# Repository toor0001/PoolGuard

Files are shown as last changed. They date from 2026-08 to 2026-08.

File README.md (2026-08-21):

# PoolGuard

**Battery-powered pool skimmer monitor for Home Assistant and ESPHome**

[Deutsch](README_DE.md) · English

PoolGuard is a DIY sensor module designed to fit precisely into the lid of an **AstralPool 17.5 L skimmer** and can be glued in place without drilling the original lid. The module measures the distance to the water surface and derives the current pool-water depth and level. It also monitors pool-water temperature. By analysing movement and short-term fluctuations at the water surface, PoolGuard can additionally estimate whether the circulation pump is running. Significantly stronger and more irregular surface movement can indicate that somebody is currently in the pool. Deep sleep and fully powering down the A02YYUW between checks are intended to make one battery charge last for an entire pool season.

## Home Assistant possibilities

PoolGuard exposes values and states that can be used for automations such as:

- switching a pool heat pump on or off based on water temperature;
- disabling the circulation pump when the water level is too low;
- sending a notification when the minimum safe water depth is crossed;
- operating a UV-C lamp only while circulation is actually detected;
- detecting unusually strong pool activity that can indicate somebody is in the pool;
- displaying current water depth, water-level percentage and estimated pool volume.

> **Name and affiliation:** PoolGuard is an independent open-source DIY project. It is not affiliated with, endorsed by or connected to any company, brand or commercial product using the PoolGuard name.

## Design Principles

1. **Reliability:** Prefer “not currently determinable with confidence” over a precise-looking state inferred from ambiguous ultrasound data.
2. **Simple:** Few settings and special cases keep this seasonal device understandable after months away.
3. **Battery efficient:** The ESP measures and decides locally. Wi-Fi/API are enabled only for relevant information or a periodic status report.
4. **Failsafe:** Errors should lead to controlled continuation, retry/backoff or deep sleep; the A02 and Wi-Fi should not remain active indefinitely.
5. **Separation of concerns:** PoolGuard determines physical states. Home Assistant handles notifications, actuators, offline monitoring and derived convenience information.

**PoolGuard/ESP:** water temperature, reliable distance/depth/level/volume, surface and pump motion, bathing activity, Low Water and Sensor Flood Risk. **Home Assistant:** dashboard, reminders, pump shutdown, high-water, pump-mismatch and offline warnings, plus an optional algae-risk advisory. Use only functions that provide clear value.

## Reliable water and motion evaluation

A water-level burst is reliable only when total motion and both burst halves remain below the active Quiet/Pump boundary. Only then are **Distance to Water**, **Water Depth**, **Water Level**, **Pool Volume** and Low Water updated. During waves these values retain the last reliable quiet measurement, while motion, pump, bathing activity and Sensor Flood Risk are still evaluated. A moving burst deliberately means **no new reliable water-level information**.

Reliable depths do not connect on every wake. A report is requested once the change from the last successfully reported reliable value reaches at least 3 mm, compared as rounded integer millimetres. Small changes accumulate: `105.0 → 104.9` no report, `104.8` no report, `104.7` report.

Person-dominated motion provides no pump ON/OFF evidence: bathing activity may be confirmed while the pump state is preserved and ambiguous pump streaks are cleared. All Pump ON/OFF and Person ON/OFF combinations are possible. During strong bathing activity, ultrasound cannot always determine the real pump state unambiguously.

The 180-minute person cooldown starts only after successful transmission. After communication failure, PoolGuard waits five real wakes before a non-critical retry uses Wi-Fi again; local measurement continues. A new person alert, Low Water OFF→ON or Sensor Flood Risk OFF→ON may bypass backoff once. If that attempt fails, normal backoff applies again.

**Sensor Flood Risk** protects the ultrasound sensor mounted close to the water; it is not a precise water-level measurement. It uses the robust lower distance quantile from at least 11 samples, so one small outlier is insufficient. The installation-dependent mechanical default clearance is 5.0 cm; clear uses 1.0 cm hysteresis and requires a reliable quiet burst. ON requires two different real wakes, and Maintenance bursts in one boot cannot count repeatedly. It adds no wakes, bursts or flash writes. The 5 cm must match the actual mounting and is unrelated to motion calibration.

An independent RTC wake sequence protects wake-based confirmations from repeated Maintenance measurements. Known physical limitation: while a continuously running pump remains above the Quiet boundary, new reliable water-level values normally cannot be obtained; Low Water is therefore typically confirmed during quiet or pump-off phases.

## Parts

| Part | Purpose | Link |
|---|---|---|
| Seeed Studio XIAO ESP32-C3 | Microcontroller / ESPHome |  |
| USB-C breakout cable | Power / connection | |
| DFRobot A02YYUW | Distance measurement to the water surface | |
| Waterproof DS18B20 | Pool-water temperature |  |
| Protected 18650 Li-ion cell | Power supply | – |
| 18650 battery holder | Battery mounting |  |
| **Pololu Mini MOSFET Slide Switch LV #2810** | Fully powers down the A02YYUW during deep sleep | [Pololu](https://www.pololu.com/product/2810) |

> **Affiliate disclosure:** Some product links may be affiliate links. If you purchase through one of them, I may receive a small commission at no additional cost to you.

## A02YYUW power switching and Controlled Mode

The A02YYUW is powered through a **Pololu Mini MOSFET Slide Switch with Reverse Voltage Protection, LV (#2810)**.

```text
XIAO 3.3 V  -------- VIN   Pololu 2810
XIAO GND    -------- GND   Pololu 2810
D2 / GPIO4  -------- ON    Pololu 2810
Pololu VOUT -------- VCC   A02YYUW
A02YYUW GND -------- GND
A02YYUW TX  -------- D7 / GPIO20 (UART RX)
A02YYUW RX  -------- D1 / GPIO3 (control/trigger line)
```

**Important:** PoolGuard uses all four A02YYUW wires. The fourth wire (A02 RX, yellow) is not left unused; it connects to **D1/GPIO3**. PoolGuard uses this line to operate the sensor in UART Controlled Mode and explicitly trigger measurements. A02 TX (white) returns the measurement frames to D7/GPIO20.

Wire colours on the verified build are: A02 red/VCC to Pololu VOUT, black/GND to common ground, white/TX to D7/GPIO20, and yellow/RX control to D1/GPIO3. Pololu ON is connected to D2/GPIO4. DS18B20 Data is connected to D3/GPIO5 with a 4.7 kΩ pull-up to 3.3 V.

- **D2 / GPIO4 HIGH:** A02YYUW powered on
- **D2 / GPIO4 LOW or high-impedance:** A02YYUW powered off
- **D1 / GPIO3:** Controlled-Mode trigger for A02 RX
- during deep sleep the A02YYUW remains unpowered

Set the Pololu's physical slide switch to off so ESPHome can control its ON pin. The DS18B20 data wire uses D3/GPIO5 with a 4.7 kΩ pull-up to 3.3 V.

The DYP UART-Controlled protocol has been successfully verified on the physical PoolGuard. GPIO3 normally stays high. After the Pololu powers the sensor and its startup delay has elapsed, the ESP sends repeated falling edges to A02 RX. Each edge explicitly requests a measurement. PoolGuard then receives the `FF Data_H Data_L Checksum` frame through A02 TX/GPIO20. There are more than 70 ms between triggers; real tests produced approximately 50 valid frames per five-second burst. The A02 is then fully powered down again. The sensor therefore does not transmit continuously and is active only during short measurement windows, which is a key part of the low-power design.

## Measurement and low-power operation

**Measurement Interval** configures the desired time from one normal wake to the next from 1 to 15 minutes; the default is 2 minutes. PoolGuard subtracts the current wake's active runtime from this period before entering deep sleep, so the measurement time is not simply added to the configured interval. Shorter intervals react faster but consume more battery.

Every normal wake initially keeps Wi-Fi disabled, powers the A02 only for its controlled-UART burst, evaluates the samples locally and switches the A02 off again. **Periodic Report Every** selects 1 to 120 wakes and defaults to 30, or about one report per hour at two-minute intervals. A cumulative difference of at least 3 rounded millimetres in reliable water depth and relevant state changes report earlier. The 180-minute person cooldown starts only after successful transmission. A failed non-critical report waits five real wakes before trying Wi-Fi again; new critical ON events may bypass this RTC-only backoff. A successful API report resets it completely.

Both interval numbers use `restore_value` and survive a complete battery disconnect. ESPHome writes them only when the user changes them. Measurements, the normal wake counter and runtime state are not written to flash each wake; the counter and pending reported states remain in RTC memory.

### Home Assistant state and sleep status

Before a connected sleep transition, PoolGuard publishes **PoolGuard Status = Sleeping / Offline** and calls `deep_sleep.enter` directly. It deliberately does not disable Wi-Fi first: ESPHome must close the native API as an expected deep-sleep disconnect. Home Assistant can then keep the last successfully reported measurement values available while the device sleeps.

The status entity reports **Initial Setup**, **Measuring**, **Reporting**, **Maintenance**, or **Sleeping / Offline**. During an ordinary offline wake, Home Assistant cannot see the brief Measuring phase because starting Wi-Fi just to announce it would defeat the low-power design; the retained status therefore remains Sleeping / Offline from HA's perspective. For the same reason there is no misleading firmware `Device Awake` binary sensor. Use HA's integration connectivity for live reachability and PoolGuard Status for the intentional operating state.

<p align="center">
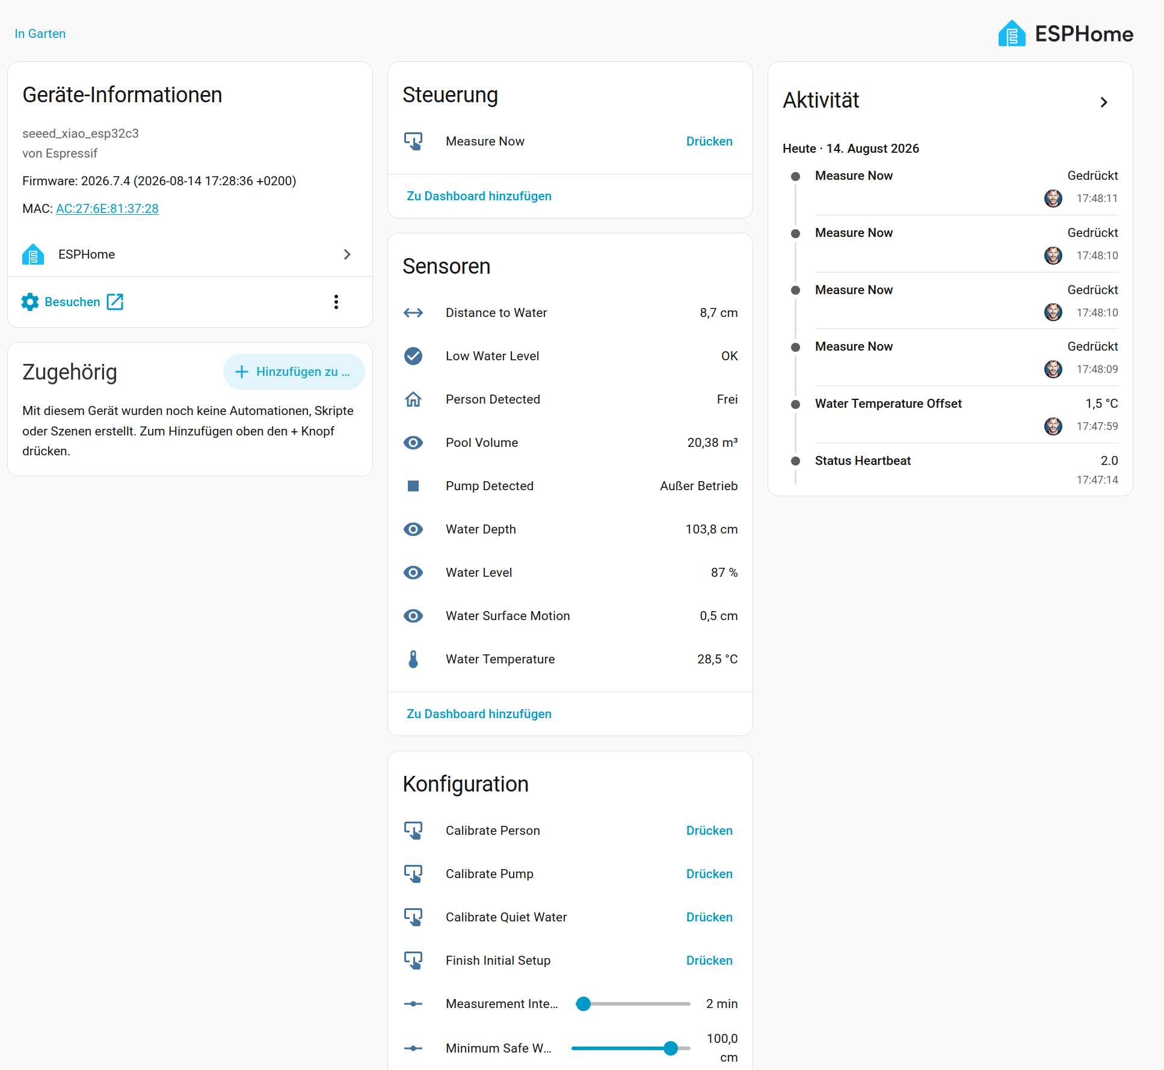
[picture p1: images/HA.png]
PoolGuard ESPHome integration in Home Assistant with retained sensor values
  <br>
  <em>PoolGuard in Home Assistant: Even while <code>Sleeping / Offline</code>, the last successfully transmitted measurements remain available.</em>
</p>

Use native HA cards in three groups: **Status** with temperature, depth, PoolGuard Status, Connection/No Data, Low Water, Sensor Flood Risk, Pump and Bathing Activity; **Algae Risk** as a Low/green, Elevated/yellow or High/red traffic-light tile without percentages; **Controls** with Maintenance, Pump and UV. A Water Depth gauge may have installation-specific colour bands but is convenience UI only—PoolGuard or HA automations make protection decisions. Keep **Status Heartbeat**/`last_updated` visible in diagnostics. No `custom:button-card` is required.

### Lovelace dashboard

<p align="center">
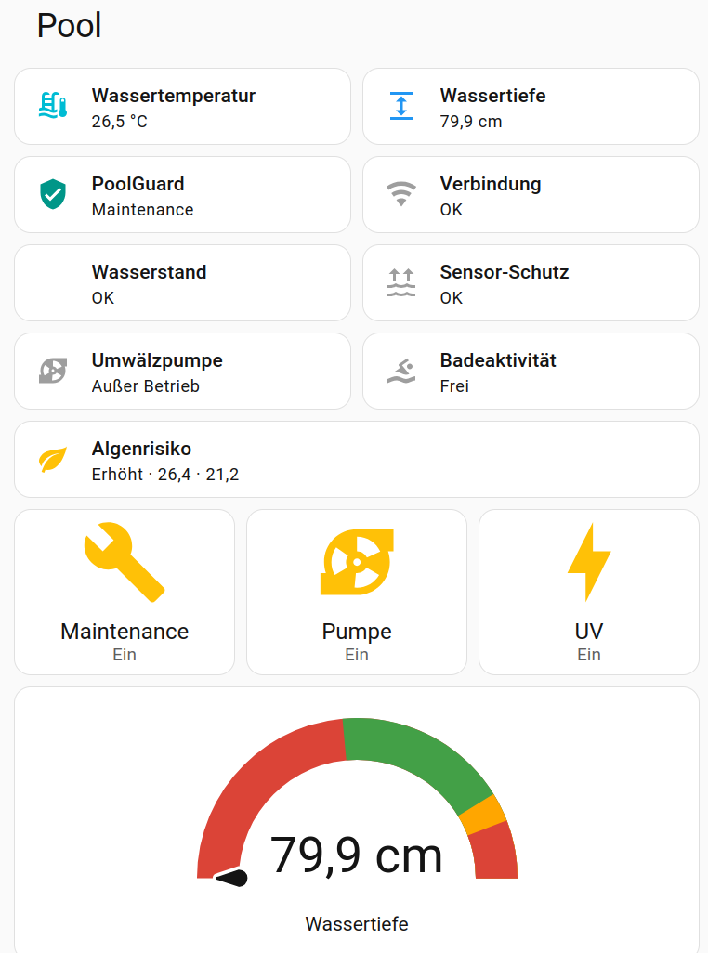
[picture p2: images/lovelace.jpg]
Final PoolGuard Lovelace dashboard with status, sensor protection, algae risk, controls and a coloured water-depth gauge
  <br>
  <em>Current PoolGuard dashboard with water temperature and depth, device and connection status, water level, sensor protection, pump, bathing activity, algae risk, Maintenance, pump and UV controls, and a coloured water-depth gauge.</em>
</p>

**Status Heartbeat** changes only after a complete successful report. Its Home Assistant `last_updated` metadata is the **Last Successful Report** time and shows the age of retained measurements without an ESP timestamp or flash write.

The persistent **Water Temperature Offset** ranges from -5.0 to +5.0 °C in 0.1 °C steps and is saved only when changed. For example, if the DS18B20 reads 25.6 °C while a reference thermometer reads 26.8 °C, set the offset to +1.2 °C; **Water Temperature** then reports 26.8 °C. It survives battery replacement. The offset is applied exactly once to a real temperature conversion; a complete report does not feed the already corrected value through the same filter a second time.

OTA remains available whenever PoolGuard is already online in Initial Setup, Maintenance Mode or a report window. The device does not create additional Wi-Fi connections solely for OTA.

## Example: Home Assistant alerts

PoolGuard can be combined with Home Assistant automations to provide several independent safety and notification functions. Keeping these automations separate makes troubleshooting easier and allows each protection function to be enabled, disabled, or adjusted independently.

Actual entity IDs depend on the device name, area and Home Assistant installation. Every ID below is illustrative and must be checked and adapted in HA. Home Assistant notifies, repeats and controls actuators without waking PoolGuard more often. The examples assume these entities:

- `binary_sensor.poolguard_person_detected`
- `binary_sensor.poolguard_low_water_level`
- `binary_sensor.poolguard_pump_detected`
- `binary_sensor.poolguard_sensor_flood_risk`
- `binary_sensor.poolguard_no_data` (HA template)
- `sensor.poolguard_water_depth`
- `sensor.poolguard_water_level`
- `switch.pool_pump`
- `notify.mobile_app_your_phone`

Replace the notification service and pump entity with your own entities.

### 1. Person / bathing activity detected

The firmware already rate-limits person-triggered reports. After one reported person/bathing event, further person-only report requests are suppressed for 180 minutes while local measurements continue. This prevents repeated notifications and unnecessary Wi-Fi/API wake-ups caused by fluctuating water movement.

```yaml
alias: PoolGuard – Person detected
description: Critical notification when PoolGuard detects person/bathing activity.
triggers:
  - trigger: state
    entity_id: binary_sensor.poolguard_person_detected
    from: "off"
    to: "on"

conditions: []

actions:
  - action: notify.mobile_app_your_phone
    data:
      title: "🚨 PoolGuard: Pool activity!"
      message: >-
        PoolGuard detected strong water-surface movement that may indicate
        a person or bathing activity in the pool.
      data:
        push:
          interruption-level: critical

mode: single
```

### 2. Low-water warning

HA notifies immediately, hourly and after an HA restart while Low Water remains active. No long `repeat`/`delay` loop is required.

```yaml
alias: PoolGuard – Low Water Warning
triggers:
  - trigger: state
    entity_id: binary_sensor.poolguard_low_water_level
    from: "off"
    to: "on"
  - trigger: time_pattern
    minutes: "0"
  - trigger: homeassistant
    event: start
conditions:
  - condition: state
    entity_id: binary_sensor.poolguard_low_water_level
    state: "on"
actions:
  - action: notify.mobile_app_your_phone
    data:
      title: "PoolGuard: Water level critical"
      message: >-
        PoolGuard has confirmed a critical water level.

        Trigger depth:
        {{ states('sensor.poolguard_low_water_trigger_depth') }} cm

        Current reliable water depth:
        {{ states('sensor.poolguard_water_depth') }} cm

        Water level:
        {{ states('sensor.poolguard_water_level') }} %
      data:
        push:
          interruption-level: critical
mode: single
```

### 3. Pump safety shutdown on low water

This automation switches the circulation pump off when PoolGuard reports a critical water level.

It also prevents the pump from being switched back on while the low-water condition remains active. This is useful when the pump is controlled by another schedule or automation that could otherwise start it again.

A critical notification is sent every time the automation actually performs a safety shutdown.

```yaml
alias: PoolGuard – Pump safety shutdown
description: >
  Switch off the pool pump when the water level is critical and prevent
  it from being switched back on while the low-water condition remains active.
  Send a critical notification for every safety shutdown.

triggers:
  - trigger: state
    entity_id: binary_sensor.poolguard_low_water_level
    from: "off"
    to: "on"
    id: low_water

  - trigger: state
    entity_id: switch.pool_pump
    from: "off"
    to: "on"
    id: pump_on
  - trigger: homeassistant
    event: start

conditions:
  - condition: state
    entity_id: binary_sensor.poolguard_low_water_level
    state: "on"

  - condition: state
    entity_id: switch.pool_pump
    state: "on"

actions:
  - action: switch.turn_off
    target:
      entity_id: switch.pool_pump

  - action: notify.mobile_app_your_phone
    data:
      title: "🚨 PoolGuard: Pump safety shutdown!"
      message: >-
        The circulation pump was automatically switched off because
        PoolGuard detected a critical water level.

        Water depth:
        {{ states('sensor.poolguard_water_depth') }} cm

        Water level:
        {{ states('sensor.poolguard_water_level') }} %
      data:
        push:
          interruption-level: critical

mode: single
```

### 4. Pump powered but no typical water movement

This is a warning only. PoolGuard cannot know for certain that no water is flowing. Causes may include pump, suction, valve position, hydraulics or calibration. It deliberately does not warn during person/bathing activity or when data is stale.

```yaml
alias: PoolGuard – Pump On Without Water Motion
triggers:
  - trigger: time_pattern
    minutes: "/1"
conditions:
  - condition: state
    entity_id: switch.pool_pump
    state: "on"
  - condition: state
    entity_id: binary_sensor.poolguard_pump_detected
    state: "off"
  - condition: state
    entity_id: binary_sensor.poolguard_person_detected
    state: "off"
  - condition: state
    entity_id: binary_sensor.poolguard_no_data
    state: "off"
  - condition: template
    value_template: >-
      {% set since = [states.switch.pool_pump.last_changed,
        states.binary_sensor.poolguard_pump_detected.last_changed,
        states.binary_sensor.poolguard_person_detected.last_changed] | max %}
      {{ now() - since >= timedelta(minutes=5) }}
  - condition: template
    value_template: >-
      {% set last = this.attributes.get('last_triggered') %}
      {{ last is none or now() - last >= timedelta(minutes=5) }}
actions:
  - action: notify.mobile_app_your_phone
    data:
      title: "PoolGuard: Pump without typical water motion"
      message: "Calibrated pump motion has been absent for at least five minutes. Check pump, flow and valve position."
mode: single
```

### 5. High water level alert

`Distance to Water` updates only from a reliable quiet burst. The example 3 cm threshold depends on installation. No Data prevents repetitions caused by an old frozen value.

```yaml
alias: PoolGuard – Pool Too Full
triggers:
  - trigger: numeric_state
    entity_id: sensor.poolguard_distance_to_water
    below: 3
  - trigger: time_pattern
    minutes: "/15"
  - trigger: homeassistant
    event: start
conditions:
  - condition: numeric_state
    entity_id: sensor.poolguard_distance_to_water
    below: 3
  - condition: state
    entity_id: binary_sensor.poolguard_no_data
    state: "off"
actions:
  - action: notify.mobile_app_your_phone
    data:
      title: "PoolGuard: Pool too full"
      message: >-
        Reliable distance to water:
        {{ states('sensor.poolguard_distance_to_water') }} cm.
        Please check the pool level.
      data:
        push:
          interruption-level: critical
mode: single
```

### 6. Sensor Flood Risk

High Water and Sensor Flood Risk differ deliberately: High Water is a precise quiet-only distance; Flood Risk protects the sensor and may inspect moving water for repeated dangerous approaches.

```yaml
alias: PoolGuard – Sensor Flood Risk
triggers:
  - trigger: state
    entity_id: binary_sensor.poolguard_sensor_flood_risk
    from: "off"
    to: "on"
  - trigger: time_pattern
    minutes: "/15"
  - trigger: homeassistant
    event: start
conditions:
  - condition: state
    entity_id: binary_sensor.poolguard_sensor_flood_risk
    state: "on"
  - condition: state
    entity_id: binary_sensor.poolguard_no_data
    state: "off"
actions:
  - action: notify.mobile_app_your_phone
    data:
      title: "PoolGuard: Sensor flood risk"
      message: >-
        Water is repeatedly getting dangerously close to the ultrasonic sensor.
        Last reliable quiet distance:
        {{ states('sensor.poolguard_distance_to_water') }} cm.
        Check PoolGuard and the pool level.
      data:
        push:
          interruption-level: critical
mode: single
```

### 7. Offline/no-data warning

The ESP being currently unavailable during deep sleep is normal. “Offline” here means no complete successful report for more than three hours. **Status Heartbeat** is the source.

```yaml
template:
  - binary_sensor:
      - name: PoolGuard No Data
        unique_id: poolguard_no_data
        state: >-
          {% set e = states.sensor.poolguard_status_heartbeat %}
          {{ e is not none
             and e.state not in ['unknown', 'unavailable']
             and (now() - e.last_updated).total_seconds() > 10800 }}
```

```yaml
alias: PoolGuard – Offline Warning
triggers:
  - trigger: state
    entity_id: binary_sensor.poolguard_no_data
    from: "off"
    to: "on"
  - trigger: time
    at: "12:00:00"
  - trigger: homeassistant
    event: start
conditions:
  - condition: state
    entity_id: binary_sensor.poolguard_no_data
    state: "on"
actions:
  - action: notify.mobile_app_your_phone
    data:
      title: "PoolGuard: No data"
      message: "No successful report for more than three hours. Check PoolGuard, Wi-Fi and battery."
mode: single
```

10800 seconds is three hours. After an HA restart, `last_updated` may initially look fresh and delay detection; no extra persistent timestamp helper is deliberately required.

### 8. Optional algae-risk indicator

PoolGuard **does not detect algae**. This is only a simplified temperature-based environmental advisory in Home Assistant, not a biological measurement, water analysis or disinfection measurement. It uses pool temperature, a real local outdoor thermometer and the maximum forecast temperature over the next 24 hours. Never derive automatic pump or chemical dosing from it.

```yaml
template:
  - triggers:
      - trigger: homeassistant
        event: start
      - trigger: time_pattern
        minutes: "/15"
    actions:
      - action: weather.get_forecasts
        target:
          entity_id: weather.home
        data:
          type: hourly
        response_variable: pool_weather
    sensor:
      - name: Pool Algae Risk
        unique_id: pool_algae_risk
        icon: mdi:algae
        state: >-
          {% set pool = states('sensor.poolguard_water_temperature') | float(none) %}
          {% set outside = states('sensor.outdoor_temperature') | float(none) %}
          {% set forecast = pool_weather['weather.home'].forecast[:24]
             if pool_weather is defined and 'weather.home' in pool_weather else [] %}
          {% set temps = forecast | map(attribute='temperature')
             | select('defined') | list %}
          {% set forecast_max = temps | max if temps | count > 0 else none %}
          {% if outside is not none and forecast_max is not none %}
            {% set ambient_peak = [outside, forecast_max] | max %}
          {% elif forecast_max is not none %}
            {% set ambient_peak = forecast_max %}
          {% else %}
            {% set ambient_peak = outside %}
          {% endif %}
          {% if pool is none %}
            Unknown
          {% elif pool >= 29 %}
            High
          {% elif pool >= 27 and ambient_peak is not none and ambient_peak >= 27 %}
            High
          {% elif pool >= 24 %}
            Elevated
          {% elif pool >= 22 and ambient_peak is not none and ambient_peak >= 28 %}
            Elevated
          {% else %}
            Low
          {% endif %}
        attributes:
          forecast_peak_24h: "{{ forecast_max }}"
          ambient_peak: "{{ ambient_peak }}"
          uv_index: "{{ state_attr('weather.home', 'uv_index') }}"
```

Logic: unknown pool temperature → Unknown; 29 °C or more → High; 27 °C or more with ambient peak at least 27 °C → High; 24 °C or more → Elevated; 22 °C or more with ambient peak at least 28 °C → Elevated; otherwise Low. Ambient peak is the higher of current local outdoor temperature and the 24-hour forecast maximum.

UV index is exposed only as an informative attribute. It is primarily a human-health indicator, is not linearly related to algae, may inhibit some algae directly, and can indirectly matter in chlorinated pools through faster free-chlorine loss. Without free chlorine, pH and disinfection reserve, a more precise “probability” would be false precision.

```yaml
alias: PoolGuard – Algae Risk Advisory
triggers:
  - trigger: state
    entity_id: sensor.pool_algae_risk
    to: "High"
  - trigger: time
    at: "12:00:00"
conditions:
  - condition: state
    entity_id: sensor.pool_algae_risk
    state: "High"
actions:
  - action: notify.mobile_app_your_phone
    data:
      title: "PoolGuard: elevated algae risk"
      message: "Temperature-based advisory: check water care and filtration time."
mode: single
```

## Maintenance Mode

Create a persistent Home Assistant helper named **PoolGuard Maintenance Mode** with entity ID `input_boolean.poolguard_maintenance_mode` (Settings → Devices & services → Helpers → Create helper → Toggle). The helper, rather than an ESPHome template switch, owns the requested state so an ON command is retained while PoolGuard is asleep and offline.

Turning the helper on is not immediate while PoolGuard sleeps. PoolGuard does not connect to Wi-Fi during each local measurement. It receives the retained request the next time the existing event-driven or periodic reporting logic connects to the Home Assistant API. With the defaults of 2 minutes and 30 wakes, the worst-case delay is approximately one hour; a state-change report can activate it earlier. **PoolGuard Status = Maintenance** confirms that the request has actually reached the device.

While Maintenance Mode is active, PoolGuard stays awake with Wi-Fi/API connected. It performs a powered A02 burst and evaluates water level, pump/activity and person/activity approximately every 5 seconds. Water temperature updates every 30 seconds. The A02 is switched off between bursts. Leaving this mode enabled greatly reduces battery life. Maintenance is really active when **PoolGuard Status** shows Maintenance, the live ESPHome log remains connected and repeated A02 measurement bursts continue to appear in the log. This makes the mode particularly suitable for OTA work and recalibration.

Turn the helper off to leave Maintenance Mode immediately. PoolGuard stops live measurements, switches the A02 off, performs final temperature housekeeping, and returns to its normal deep-sleep cycle without rebooting. The local active flag is intentionally not restored after an unexpected reset: battery-saving operation is the fail-safe default, while the retained HA helper request can be accepted again at a later normal API connection.

Maintenance Mode is a runtime Home Assistant control and does not require reflashing. It remains distinct from Initial Setup Mode, and checking its helper does not add Wi-Fi connections to the local measurement cycle. OTA is available while Maintenance is active; turn the helper back off after OTA or calibration so PoolGuard returns to deep sleep and battery operation.

## Initial Setup Mode

On the first boot in factory state, PoolGuard automatically enters Initial Setup Mode. A flash-backed `initial_setup_completed` flag defaults to false, so Wi-Fi and the Home Assistant API remain enabled and deep sleep is prevented. The A02 stays powered off while idle; it is powered only for an explicit measurement or calibration action. The DS18B20 remains available.

Commissioning requires only one firmware flash:

1. Flash PoolGuard and add it to Home Assistant.
2. Set the water-level reference and minimum safe water depth.
3. Calibrate Quiet Water, Pump and Person if possible.
4. Press **Finish Initial Setup**.

PoolGuard requires a valid water-level reference before it accepts the finish command. Incomplete motion calibration is allowed; a warning is logged and the fallback thresholds remain active. The completion flag is then saved to flash, the A02 is switched off, and normal battery-saving operation begins. Every later power-up, reset and deep-sleep wake starts directly in normal mode. No second flash is required.

To commission the device again, press **Reset Initial Setup** twice within 10 seconds. This confirmation protects against an accidental press. PoolGuard immediately clears the persistent flag, stays awake with Wi-Fi/API enabled, and keeps the A02 off until a measurement or calibration is requested. Existing calibration values are not erased automatically.

## Water-level reference calibration

PoolGuard no longer requires separate "empty" and "full" distance calibration points. **One known real water depth is enough.**

During the automatically entered Initial Setup Mode:

1. Measure the **actual current water depth** in the pool in centimetres.
2. Enter it in **Reference Water Depth**.
3. Press **Measure Now** and check that the A02 distance is plausible.
4. Press **Set Water Level Reference** while the water remains at that level.
5. Set **Minimum Safe Water Depth** to the lowest real depth at which the skimmer can still supply the circulation pump safely.
6. With the pump off, nobody in the pool and the water as calm as possible, press **Calibrate Quiet Water**.
7. Run the pump with nobody in the pool and press **Calibrate Pump**.
8. Create typical swimming/bathing movement and press **Calibrate Person**.
9. Review the three motion profiles and automatically learned thresholds.
10. Press **Finish Initial Setup**.

From then on, PoolGuard calculates the current depth from the change in A02 distance. The distance from the sensor to the pool bottom does not have to be measured separately.

The calculation has been tested on the real pool: a reference depth of 105.5 cm subsequently produced approximately 105.4 cm. Water reference, minimum safe depth, all three motion profiles, learned thresholds and temperature offset are flash-persistent and survive battery replacement.

The default geometry in the YAML is a round pool with **5.0 m diameter** and **120 cm maximum depth**. `Water Level` is calculated as a percentage of that configured maximum depth. `Pool Volume` assumes a cylindrical pool and uses the current measured water depth. With the default geometry, 120 cm corresponds to approximately **23.56 m³**. For another pool, change `pool_diameter_m` and `pool_max_depth_cm` in the YAML. Pools with non-cylindrical bottoms will only get an approximate volume.

## Guided motion calibration

Pump and pool-activity detection depend heavily on the actual skimmer, pump flow, water level and pool geometry. PoolGuard therefore includes guided calibration instead of relying only on fixed thresholds.

In Initial Setup Mode, run these three buttons in order if possible:

1. **Calibrate Quiet Water** – pump off and nobody in the pool.
2. **Calibrate Pump** – circulation pump running, nobody in the pool.
3. **Calibrate Person** – normal swimming/bathing movement in the pool.

Each phase measures about 60 seconds and stores the median motion profile. Motion is evaluated from a trimmed sample span so single outliers or splashes have less influence than a raw min/max range. If the profiles are clearly ordered `quiet < pump < person`, PoolGuard automatically calculates the pump and person/activity thresholds. If they overlap, the previous or fallback thresholds remain active.

The three values describe increasing water-surface movement: Quiet Motion is baseline noise, Pump Motion is normal circulation, and Person Motion is typical bathing activity. Profiles of Quiet 0.50 cm, Pump 0.90 cm and Person 1.45 cm are formally ordered. PoolGuard puts the pump threshold halfway between Quiet and Pump (0.70 cm), but the person entry threshold 65% of the way from Pump to Person (about 1.26 cm); clearing uses the midpoint. Firmware checks strict ordering only, not statistical separation. Closely spaced profiles can therefore be valid yet hard to distinguish in practice.

### Recalibrating individual profiles later

A complete recalibration is not required when only one real-world operating condition has changed. The three profiles can be measured **individually**. Turn on the Maintenance helper and wait until **PoolGuard Status = Maintenance**, then run only the calibration you want to update.

Example: if the running circulation pump is incorrectly classified as a person/bathing activity, leave the pump running under normal real conditions and run **Calibrate Pump** again. Quiet Water and Person do not automatically need to be recalibrated. Afterwards review `Calibration Pump Motion`, `Calibration Person Motion`, `Active Pump Motion Threshold` and `Active Person Motion Threshold`. If the new pump profile reaches or exceeds the person profile, the motion patterns overlap; in that case the person calibration should also be reviewed under realistic conditions.

**Reset Motion Calibration** is not required for normal recalibration. Use it only when you intentionally want to discard all stored motion profiles. After recalibration, turn the Maintenance helper off so PoolGuard returns to normal deep-sleep operation.

Motion calibration is optional for finishing initial setup. If it cannot be completed, PoolGuard logs a warning and continues with its fallback thresholds. After calibration, press **Finish Initial Setup** to begin normal battery-saving operation.

> **Important:** PoolGuard does not detect a person directly. It classifies water-surface motion. Pump/activity detection is therefore an experimental indication and must not be used as a safety system or substitute for pool supervision.

## Mechanical concept

The housing body sits inside the skimmer and is fixed to the side ribs using suitable neutral-curing silicone. The original centre rib remains intact. The body is intentionally **slightly sloped towards the inside of the skimmer**, so any water that reaches the housing can drain back into the skimmer instead of collecting on the body. The removable lower lid carries the electronics:

- battery holder and ESP on the dry/internal side;
- A02YYUW on the water-facing side;
- feed-through for the DS18B20 cable.

The current printable files are available in [`3D-Files/`](3D-Files/). I use a Bambu Lab A1 Mini.

<p align="center">
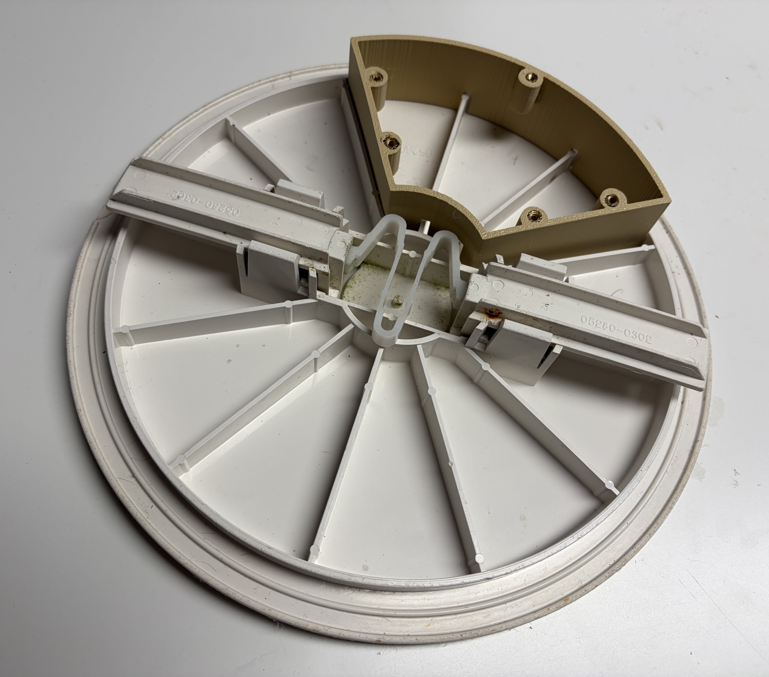
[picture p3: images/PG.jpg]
PoolGuard mechanical housing concept
  <br>
  <em>PoolGuard housing concept for the skimmer lid and removable electronics carrier.</em>
</p>

## Moisture protection and silica gel

PoolGuard sits only a few centimetres above the water surface. Even without direct water ingress, high humidity and temperature changes can cause condensation. A small closed **silica-gel desiccant sachet** inside the electronics compartment is therefore useful as an additional moisture buffer. For the small PoolGuard enclosure, roughly **5–10 g** in total is a practical starting point if the sachet can be secured without stressing components or electrical contacts.

Silica gel is not chemically "used up", but it gradually becomes saturated with water and then loses its effectiveness. Regenerable sachets, ideally with a humidity indicator, can be inspected during seasonal maintenance and dried/regenerated according to the manufacturer's instructions or replaced. There is no honest fixed lifetime in days for PoolGuard: it depends heavily on how open the enclosure is to humid outside air, pool and air temperature, and day/night temperature swings.

Do not use loose granules and **do not use table salt**. Silica gel also does not replace protection against direct splashes or dripping water. The complete electronics enclosure should not simply be covered in silicone or fully potted in epoxy; obvious ingress paths and cable entries can instead be sealed selectively.

More detail: [Moisture, condensation and silica gel](docs/ENVIRONMENT.md).

## Final assembly

<table>
  <tr>
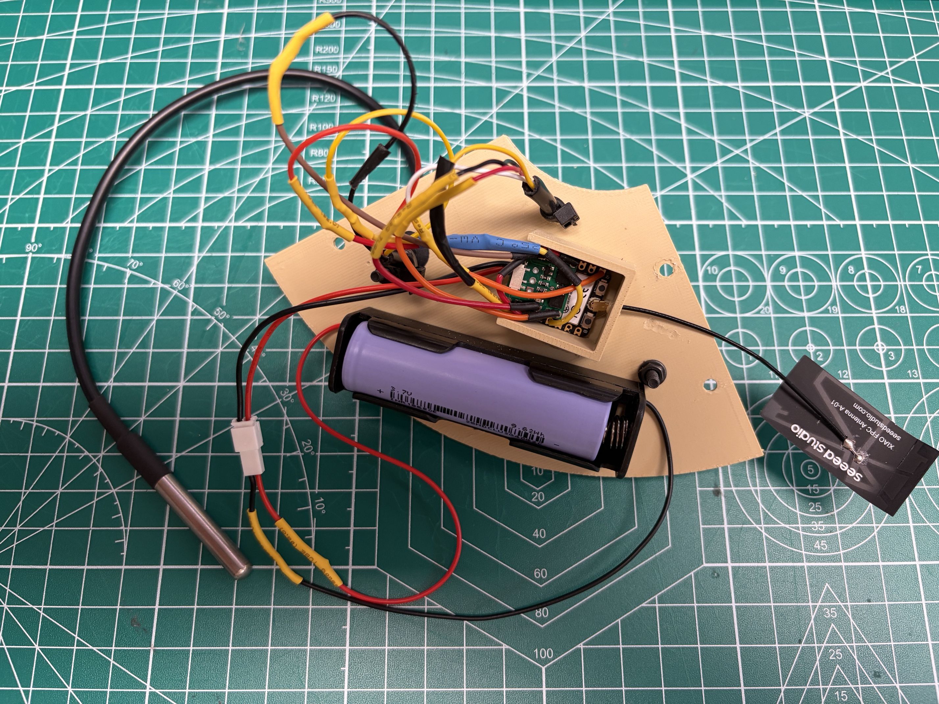
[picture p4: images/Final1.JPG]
PoolGuard electronics carrier with battery, controller and sensors
    <td width="50%" align="center"></td>
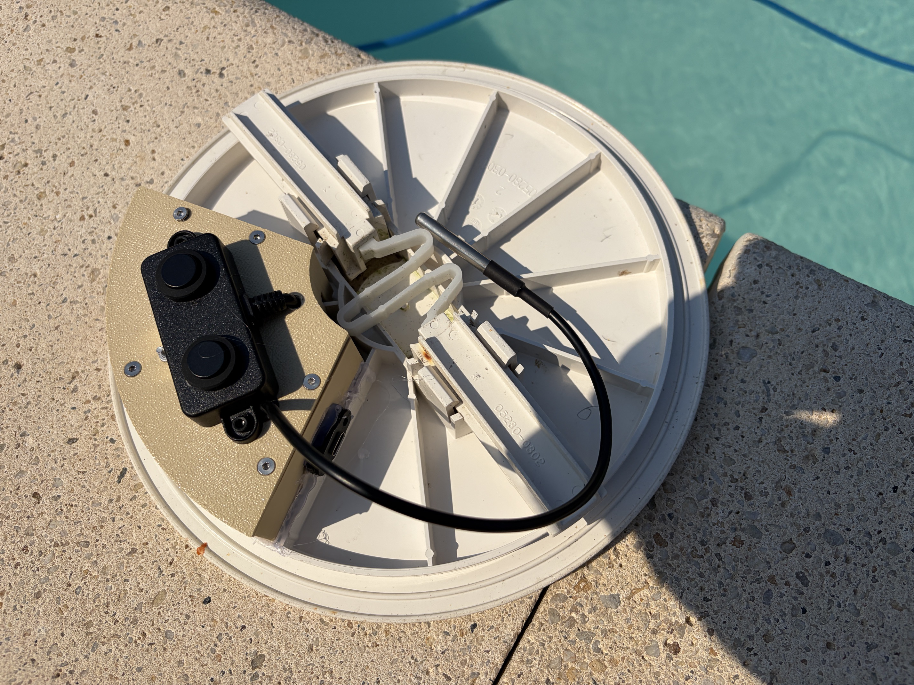
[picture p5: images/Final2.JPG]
PoolGuard sensor carrier installed on the skimmer lid
    <td width="50%" align="center"></td>
  </tr>
  <tr>
    <td align="center"><em>Wired electronics carrier with 18650 battery, XIAO controller, A02 and DS18B20.</em></td>
    <td align="center"><em>Sensor side of the completed carrier fitted to the original skimmer lid.</em></td>
  </tr>
</table>

## Seasonal operation

At season start: (1) mount PoolGuard and inspect battery, seals, cable entries and silica gel, (2) verify water reference and geometry, (3) set Minimum Safe Water Depth, (4) calibrate Quiet, (5) Pump and (6) Person/Activity, (7) disable Maintenance and (8) confirm deep sleep. Normal operation is always wake → measure → decide locally → report a relevant change or periodic status → sleep. Maintenance and Initial Setup deliberately keep the device awake for service/commissioning and use far more energy; do not use them normally. There is no exact battery-level sensor. No Data/Heartbeat indirectly covers an empty battery, Wi-Fi/API trouble or device failure without promising remaining runtime. At season end, remove and dry the device, inspect for corrosion and store the battery appropriately.

## What PoolGuard does not do

PoolGuard is not a certified person, drowning, overflow or dry-run safety system and cannot replace supervision or compliant electrical/mechanical protection. It has no camera: “Person detected” means strong water movement. It measures neither algae, chlorine nor pH, calculates no exact algae probability and has no real battery gauge. During arbitrary strong movement neither pump state nor a new water level is always determinable; HA retains the last quiet level. Pump/no-motion mismatch is a warning only and does not automatically stop the pump.

## Backlog

### Switchable battery voltage measurement

A future hardware revision may add measurement of the actual battery voltage. Instead of using a permanently connected resistor divider, the measurement path should be enabled through a MOSFET or load switch only while a measurement is being taken. This prevents the voltage divider from causing continuous quiescent current during deep sleep.

After a short settling time, the battery voltage could be sampled several times through an ADC input to obtain a stable reading. The complete measurement path would then be disconnected from the battery again.

This change is deliberately not implemented in the current hardware revision because it would require additional hardware. The existing `Status Heartbeat` and Home Assistant `No Data` monitoring already provide a reliable way to detect when PoolGuard stops reporting because of an empty battery, communication problems or another device failure.

Any battery percentage derived from the measured voltage would also remain an estimate: the actual state of charge of a single Li-ion cell cannot be determined precisely from voltage alone.

## Technical settings

Normal users operate Maintenance and commissioning/calibration values. HA-adjustable settings, stored only when changed, are **Measurement Interval** (1–15, default 2 minutes), **Periodic Report Every** (1–120, default 30 wakes), reference, safe minimum depth and temperature offset. YAML substitutions cover technical tuning: 5 s A02 burst, 200 ms startup, 2 ms trigger LOW, an approximately 80 ms trigger cadence (2 + 78 ms), confirmation cycles, 1.5/3.0 cm fallbacks, 180-minute cooldown, five backoff wakes, pool geometry, and 5.0 cm Flood Risk distance with 1.0 cm clear hysteresis. The 3 mm report threshold is fixed in code. Flood Risk is mechanical clearance and must suit mounting height.

## Quick start

1. Download and print the current files from `3D-Files/`.
2. Use `esphome/secrets.example.yaml` as a template for your own ESPHome secrets. PoolGuard uses the device-specific `poolguard_api_encryption_key` and `poolguard_ota_password` names; Wi-Fi secrets may be shared.
3. Review pins, pool geometry and calibration values in `esphome/poolguard.yaml`.
4. Flash the XIAO ESP32-C3 via USB.
5. On the automatic first boot, add PoolGuard to Home Assistant.
6. Measure the real water depth, enter **Reference Water Depth** and press **Set Water Level Reference**.
7. Set **Minimum Safe Water Depth** for the real skimmer/pump installation.
8. Run the quiet-water, pump and person/activity calibration if possible.
9. Press **Finish Initial Setup**. PoolGuard stores completion and starts normal low-power operation; no second flash is required.

## Safety

- Use a protected, reputable 18650 cell.
- Do not short, crush, reverse or charge the cell unattended.
- Keep the electronics protected from condensation and splash water.
- Use the Pololu 2810 to fully power down the A02YYUW during deep sleep.
- Treat pump and person/activity detection as indications only, never as the sole basis for a safety-critical shutdown or monitoring function.
- This is an experimental DIY project. Build, install and operate it at your own risk.

## Support

<a href="https://paypal.me/toor0001/5">Buy me a coffee via PayPal</a>

## License

Software and documentation are released under the MIT License. CAD files are currently prototype files and may receive a separate hardware license before the first stable release.

## Development Note

This project was created as part of a collaborative **vibe-coding workflow** with **ChatGPT** and **OpenAI Codex**. Both tools were used for code generation, reviews, troubleshooting and documentation.

Hardware assembly, integration decisions, practical testing and final responsibility for the project remain with the project operator.

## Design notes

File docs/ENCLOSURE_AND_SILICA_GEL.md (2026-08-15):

# Enclosure moisture protection and silica gel

PoolGuard is installed only a few centimetres above the pool-water surface. The electronics therefore have to cope with high relative humidity, temperature changes and possible condensation even when they are protected from direct splashes.

## Do not pot the complete enclosure

Do not fill the complete electronics compartment with epoxy and do not simply coat the whole enclosure in silicone. Full potting makes later repair difficult, can trap moisture that is already inside and can create mechanical stress around connectors and cables. Silicone is useful selectively at cable entries, seams and other known splash paths, but it should not be used as a substitute for a deliberate enclosure design.

The existing openings around the skimmer-lid ribs mean that the compartment is not hermetically sealed. This is not automatically a problem: preventing liquid water and splashes from reaching the PCB is more important than trying to make a small DIY enclosure perfectly airtight. Any opening should be arranged so that water cannot run directly onto the electronics and so that accumulated water cannot remain trapped inside.

## Silica gel

A small **silica-gel desiccant sachet** inside the electronics compartment is a useful additional precaution. Use a proper porous sachet; do not pour loose beads into the enclosure and do not use table salt. The sachet should be fixed so it cannot touch moving parts, connectors or exposed contacts and cannot fall into the pool.

Silica gel is **not permanent**. It adsorbs water from the enclosed air until it approaches saturation. How long that takes cannot be specified as a fixed number of days because it depends strongly on:

- the amount of silica gel;
- how open the enclosure is to ambient air;
- pool-water and air temperature;
- daily temperature swings and condensation;
- how often the enclosure is opened.

In a nearly sealed small box it can remain useful for months. In a ventilated box above warm pool water it can saturate much faster because new humid air continuously enters. For PoolGuard it should therefore be regarded as a **replaceable/regenerable moisture buffer**, not as the primary waterproofing method.

Indicator silica gel is especially convenient because its colour shows when regeneration is required. Follow the manufacturer's regeneration temperature and time; many reusable silica-gel products can be dried and reused repeatedly. Do not assume one universal oven temperature, because sachet materials and indicator chemistry differ.

## Practical recommendation for PoolGuard

1. Keep direct rain, splashes and dripping water away from the electronics.
2. Seal obvious cable-entry and seam leak paths selectively where useful.
3. Do not completely encapsulate the assembled electronics in silicone or epoxy.
4. Add a small replaceable silica-gel sachet as a secondary moisture buffer.
5. Inspect the enclosure occasionally for condensation, corrosion or a saturated indicator sachet, especially after large day/night temperature changes.
6. Replace or regenerate the silica gel when its indicator shows saturation or when moisture is found inside.

Silica gel reduces humidity peaks but cannot compensate for an enclosure into which liquid water can enter.

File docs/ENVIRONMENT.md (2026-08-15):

# PoolGuard – Moisture, condensation and silica gel

PoolGuard is installed in the skimmer only a few centimetres above the water surface. The electronics are therefore exposed to persistently high relative humidity and, especially with warm pool water and cooler nights, an increased risk of condensation.

## Basic approach

The electronics enclosure should keep direct splashes and droplets away from the electronics. Fully potting the complete assembly in epoxy is not part of the normal build: it would unnecessarily complicate repairs, battery replacement, USB access and later modifications. Completely covering the enclosure in silicone is likewise not required.

Pay particular attention to openings, cable entries, screw locations and the existing louvre slots. Direct water ingress is more critical than ordinary humid air. Condensation can nevertheless occur when humid air inside the enclosure cools below its dew point.

## Silica gel as an additional moisture buffer

A small **silica-gel desiccant sachet** inside the electronics enclosure is useful as an additional moisture buffer. For the small PoolGuard enclosure, one or two small sachets totalling roughly 5–10 g are a practical starting point if they can be secured without stressing components or electrical contacts.

Silica gel does not prevent direct water ingress and is not a substitute for sensible sealing. It does, however, adsorb water vapour from the enclosed air and can therefore reduce the risk of condensation.

### Does silica gel get used up?

Silica gel is not simply chemically consumed, but its pores gradually fill with water. Once saturated, it can absorb very little additional moisture and therefore loses its protective effect. How quickly this happens depends on how much humid outside air enters the enclosure and on temperature/humidity cycling.

In a non-hermetic enclosure, silica gel should therefore be treated as a **maintenance item**. Regenerable sachets are preferable, ideally with a humidity indicator. When PoolGuard is opened for seasonal maintenance, inspect the sachet and dry/regenerate it according to the manufacturer's instructions or replace it if necessary.

> Do not install loose silica-gel granules where they could reach the PCB, connectors or battery. A closed, vapour-permeable desiccant sachet is preferable.

## Do not use table salt

Ordinary table salt is not a suitable replacement for silica gel. At high humidity salt can take up water and may form a conductive salt solution. Such a solution near the PCB, ESP32, battery or contacts significantly increases corrosion and short-circuit risk.

## Practical recommendation

- Protect the electronics from direct splashes and droplets.
- Seal cable entries and obvious ingress paths cleanly.
- Avoid full epoxy potting while serviceability is desired.
- Add a small closed silica-gel sachet as an additional humidity buffer.
- Prefer regenerable silica gel with a humidity indicator.
- Inspect the desiccant during seasonal maintenance and regenerate or replace it when saturated.
- Do not place loose table salt inside the electronics enclosure.

Silica gel is therefore an additional protective measure, not PoolGuard's primary enclosure seal.

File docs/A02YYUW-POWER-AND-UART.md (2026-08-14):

# A02YYUW / DYP-A02 – Stromversorgung, Pololu und UART-Varianten

Diese Notiz dokumentiert die für PoolGuard relevante Verdrahtung und die Unterscheidung zwischen **UART Auto Output** und **UART Controlled Output** des DYP-A02.

## Verdrahtung / Aderfarben

Für die hier verwendete UART-Kabelvariante gilt:

| Ader | Sensorfunktion | PoolGuard |
|---|---|---|
| Rot | VCC | Pololu VOUT |
| Schwarz | GND | gemeinsames GND |
| Gelb | RX | XIAO D1 / GPIO3 (Trigger-Ausgang) |
| Weiß | TX | XIAO D7 / GPIO20 (UART RX des ESP32-C3) |

Der Pololu Mini MOSFET Slide Switch LV #2810 wird von PoolGuard über D2 / GPIO4 (`ON`) gesteuert. Seine Aufgabe ist ausschließlich die **harte Stromabschaltung des A02**. Im Deep Sleep bleibt der A02 dadurch vollständig stromlos.

## Warum der Pololu trotz niedrigem Sensor-Standby verwendet wird

Der DYP-A02 ist bereits auf niedrigen Ruhestrom ausgelegt; für die UART-Controlled-Variante wird ein sehr niedriger Standby-Verbrauch spezifiziert. PoolGuard besitzt den Pololu jedoch bereits und verwendet ihn bewusst weiter:

1. Der A02 wird während des ESP32-C3-Deep-Sleep vollständig von der Versorgung getrennt.
2. Es gibt keinen unbekannten Restverbrauch des Sensors zwischen Wake-Zyklen.
3. Das Verhalten ist unabhängig davon, wie zuverlässig eine konkrete A02-Charge ihren internen Sleep-/Standby-Modus erreicht.
4. Die vorhandene Hardware muss nicht umgebaut werden.

Der Pololu ersetzt jedoch **nicht** die UART-Betriebsart des Sensors. Er schaltet nur dessen Versorgung.

## UART Auto Output vs. UART Controlled Output

DYP bietet den A02 in unterschiedlichen, beim Kauf festgelegten Ausgangsvarianten an. Diese Varianten sind nicht nur unterschiedliche Softwaremodi desselben Geräts.

### UART Auto Output

Nach dem Einschalten beginnt der Sensor selbstständig mit Messungen und sendet die Ergebnisse über TX. RX dient bei dieser Variante zur Auswahl des Ausgabeverhaltens (processed/stabiler bzw. real-time, abhängig vom konkreten Datenblatt).

Für PoolGuard bedeutet das:

1. GPIO4 schaltet den Pololu ein.
2. Der A02 erhält Versorgung.
3. Der ESP wartet auf die automatisch eintreffenden UART-Frames an GPIO20.
4. Nach dem Messburst schaltet GPIO4 den Pololu wieder aus.

**Hier ist kein zusätzlicher UART-Trigger erforderlich.**

### UART Controlled Output

Bei der Controlled-Variante reicht das Einschalten der Versorgung **nicht** aus, um eine Entfernungsmessung auszulösen. Eine Messung wird über RX getriggert (laut DYP-Dokumentation durch eine fallende Flanke bzw. geeignete serielle Aktivität). Anschließend gibt TX genau den Messwert aus.

Für PoolGuard bedeutet das:

1. GPIO4 schaltet den Pololu ein.
2. Der A02 erhält Versorgung.
3. PoolGuard muss zusätzlich RX des A02 ansteuern und für jede gewünschte Messung triggern.
4. TX des A02 liefert das Messergebnis an GPIO20.
5. Nach dem Messburst schaltet GPIO4 den Pololu wieder aus.

**Der Pololu macht die Controlled-Ansteuerung also nicht überflüssig.** Power-On und Measurement-Trigger sind zwei verschiedene Vorgänge.

## Welche Variante besitzt der vorhandene Sensor?

Die ursprüngliche Bestellung bezeichnet die Variante lediglich als **“Black UART”**. Daraus lässt sich nicht sicher ableiten, ob es sich um UART Auto oder UART Controlled handelt. Die ursprüngliche Händlerseite ist nicht mehr verfügbar.

Deshalb darf die Firmware nicht allein aufgrund der Kabelfarben auf Controlled oder Auto umgestellt werden.

Praktischer Identifikationstest:

1. Rot an Pololu VOUT, Schwarz an GND und Weiß/TX an GPIO20 anschließen.
2. Gelb/RX zunächst isoliert und zugänglich lassen.
3. A02 über den Pololu einschalten.
4. Prüfen, ob ohne RX-Ansteuerung gültige UART-Distanzframes eintreffen.

Wenn nach dem Einschalten selbstständig fortlaufend gültige Frames eintreffen, spricht das für **UART Auto Output**. Wenn bei sicher korrekter Versorgung und TX-Verbindung keine Messframes eintreffen, muss die Controlled-Variante geprüft und RX als Trigger angeschlossen werden.

Gelb/RX deshalb vor Abschluss dieses Tests **nicht abschneiden**.

## Konsequenz für die aktuelle PoolGuard-Firmware

Die aktuelle Firmware implementiert **UART Controlled Output**: `A02 RX` ist mit
XIAO D1 / GPIO3 verbunden und wird nach dem Einschalten des Sensors wiederholt
mit fallenden Flanken getriggert. `A02 TX` liefert die Antwort über GPIO20. Der
Pololu bleibt bestehen und schaltet weiterhin die komplette A02-Versorgung
zwischen den Wake-Zyklen ab.

Die genaue Sensorvariante und das Controlled-UART-Verhalten müssen am realen
Prototyp weiterhin verifiziert werden. Bis dahin Gelb/RX nicht entfernen oder
fest für eine Auto-Output-Variante umverdrahten.

## UART-Daten

Der A02 überträgt Distanzdaten als UART-Frame mit Startbyte, High-/Low-Byte der Distanz und Prüfsumme. Die Distanz ergibt sich in Millimetern aus `Data_H * 256 + Data_L`. PoolGuard soll nur Frames mit gültiger Prüfsumme und plausibler Distanz akzeptieren.

Wichtig: Baudrate und exaktes Timing müssen zum Datenblatt der tatsächlich vorhandenen A02-Version passen; unterschiedliche DYP-Dokumentstände und Produktvarianten dürfen nicht ungeprüft miteinander vermischt werden.

## DS18B20 – zur Abgrenzung

Der Wassertemperaturfühler ist unabhängig vom A02 verdrahtet:

- Rot -> 3.3 V
- Schwarz -> GND
- Gelb/DATA -> D3 / GPIO5
- 4.7 kOhm Pull-up zwischen DATA und 3.3 V

Der DS18B20 bleibt versorgt; der Pololu schaltet ausschließlich den A02.

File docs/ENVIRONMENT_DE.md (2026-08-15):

# PoolGuard – Feuchtigkeit, Kondensation und Silicagel

PoolGuard sitzt im Skimmer nur wenige Zentimeter über der Wasseroberfläche. Dadurch ist die Elektronik einer dauerhaft hohen relativen Luftfeuchtigkeit und – besonders bei warmem Poolwasser und kühleren Nächten – einem erhöhten Kondensationsrisiko ausgesetzt.

## Grundprinzip

Das Elektronikgehäuse sollte Spritzwasser möglichst fernhalten. Gleichzeitig ist ein vollständiges Vergießen der gesamten Elektronik mit Epoxidharz für den normalen Aufbau nicht vorgesehen: Reparaturen, Akkuwechsel, USB-Zugang und spätere Änderungen würden dadurch unnötig erschwert. Auch ein nachträgliches vollständiges Einschmieren des gesamten Gehäuses mit Silikon ist nicht erforderlich.

Besonders zu beachten sind Öffnungen, Kabeldurchführungen, Schraubstellen und die vorhandenen Lamellenschlitze. Direkter Wassereintritt ist kritischer als normale feuchte Luft. Kondensation kann trotzdem auftreten, wenn feuchte Luft im Gehäuse bei sinkender Temperatur den Taupunkt erreicht.

## Silicagel als zusätzlicher Feuchtepuffer

Ein kleiner Beutel **Silicagel** im Elektronikgehäuse ist als zusätzlicher Feuchtepuffer sinnvoll. Für das kleine PoolGuard-Gehäuse sind beispielsweise ein oder zwei kleine Beutel mit insgesamt ungefähr 5–10 g ein praktikabler Ausgangspunkt, sofern sie mechanisch sicher untergebracht werden können und keine Bauteile oder Kontakte belasten.

Silicagel verhindert keinen direkten Wassereintritt und ersetzt keine sinnvolle Abdichtung. Es bindet jedoch Wasserdampf aus der eingeschlossenen Luft und kann dadurch das Kondensationsrisiko reduzieren.

### Wird Silicagel verbraucht?

Silicagel wird chemisch nicht einfach „aufgebraucht“, aber seine Poren nehmen mit der Zeit Wasser auf. Ist das Material gesättigt, kann es praktisch keine zusätzliche Feuchtigkeit mehr aufnehmen und verliert damit seine Schutzwirkung. Wie schnell das geschieht, hängt davon ab, wie viel feuchte Außenluft in das Gehäuse gelangt und wie stark die Temperatur- und Feuchtigkeitsschwankungen sind.

Bei einem nicht hermetisch dichten Gehäuse sollte Silicagel deshalb als **Wartungsteil** betrachtet werden. Sinnvoll sind regenerierbare Beutel, idealerweise mit Feuchtigkeitsindikator. Beim saisonalen Öffnen des PoolGuard kann der Beutel kontrolliert und bei Bedarf entsprechend den Herstellerangaben getrocknet/regeneriert oder ersetzt werden.

> Silicagel niemals lose so einbauen, dass Granulat an Leiterplatte, Steckverbinder oder Akku gelangen kann. Ein geschlossener, dampfdurchlässiger Trockenmittelbeutel ist vorzuziehen.

## Kein Kochsalz verwenden

Normales Kochsalz ist kein geeigneter Ersatz für Silicagel. Bei hoher Feuchtigkeit kann Salz Wasser aufnehmen; dabei kann eine leitfähige Salzlösung entstehen. Eine solche Lösung in unmittelbarer Nähe von Leiterplatte, ESP32, Akku und Kontakten erhöht das Korrosions- und Kurzschlussrisiko erheblich.

## Praktische Empfehlung

- Elektronik vor direktem Spritz- und Tropfwasser schützen.
- Kabeldurchführungen und offensichtliche Eintrittsstellen sauber ausführen.
- Keine komplette Epoxid-Vergussmasse verwenden, solange Wartbarkeit gewünscht ist.
- Einen kleinen geschlossenen Silicagel-Beutel als zusätzlichen Feuchtepuffer einsetzen.
- Bevorzugt regenerierbares Silicagel mit Feuchtigkeitsindikator verwenden.
- Silicagel beim saisonalen Öffnen prüfen und bei Sättigung regenerieren oder ersetzen.
- Kein loses Kochsalz in das Elektronikgehäuse geben.

Silicagel ist damit eine zusätzliche Schutzmaßnahme – nicht die primäre Abdichtung des PoolGuard.

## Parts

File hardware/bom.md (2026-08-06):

# Bill of materials / Stückliste

This list describes the current PoolGuard prototype. Exact connectors, cable lengths and fasteners may change after the mechanical fit test.

| Qty | Component | Notes |
|---:|---|---|
| 1 | Seeed Studio XIAO ESP32-C3 | Version with external antenna connector preferred |
| 1 | 2.4 GHz adhesive antenna | U.FL/IPEX connector matching the XIAO board |
| 1 | DFRobot A02YYUW | Waterproof UART ultrasonic distance sensor |
| 1 | Waterproof DS18B20 probe | Three-wire version recommended |
| 1 | 18650 holder | Single-cell holder, approximately 70 × 20 × 19 mm, centre screw hole |
| 1 | Protected 18650 cell | Reputable manufacturer and suitable capacity |
| 1 | Pololu Mini MOSFET Slide Switch LV #2810 | High-side switching of the A02 supply; final wiring still to be validated |
| 1 | 4.7 kΩ resistor | DS18B20 data pull-up to 3.3 V |
| 1 | Optional on/off switch | Useful for transport and servicing |
| 4 | M2.5 screws | Removable PoolGuard housing lid; length depends on final bosses |
| 2 | M3 screws, washers and nuts | A02 mounting; confirm against the final printed lid |
| 1 | Small screw for battery holder | Match the centre hole in the actual holder |
| — | Heat-shrink tubing / wire | Moisture-resistant wiring and strain relief |
| — | Neutral-curing silicone | Suitable for permanent damp conditions and compatible with the skimmer plastic |
| — | PETG or ASA filament | Preferred over untreated PLA for the final outdoor part |

## Not yet final

- final Pololu 2810 wiring/current measurement
- charger arrangement and charging connector
- final screw lengths
- gasket or sealing method between body and removable lid

Do not purchase large quantities from this list before the first complete prototype has been validated.

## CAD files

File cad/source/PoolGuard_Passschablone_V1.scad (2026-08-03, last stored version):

// PoolGuard Passschablone V1
// Fit-test frame for skimmer compartments 3 and 4.
// This is not the final housing.

$fn = 180;

lid_diameter = 242.0;
compartment_depth = 78.5;
radial_clearance = 0.5;
angular_clearance = 0.6;
wall = 2.0;
height = 5.0;

outer_radius = lid_diameter / 2 - radial_clearance;
inner_radius = lid_diameter / 2 - compartment_depth + radial_clearance;
start_angle = -30 + angular_clearance;
end_angle = 30 - angular_clearance;

module sector_2d(ri, ro, a0, a1, step = 0.5) {
    polygon(points = concat(
        [for (a = [a0 : step : a1]) [ro * cos(a), ro * sin(a)]],
        [for (a = [a1 : -step : a0]) [ri * cos(a), ri * sin(a)]]
    ));
}

linear_extrude(height = height)
difference() {
    sector_2d(inner_radius, outer_radius, start_angle, end_angle);
    sector_2d(
        inner_radius + wall,
        outer_radius - wall,
        start_angle + 0.8,
        end_angle - 0.8
    );
}

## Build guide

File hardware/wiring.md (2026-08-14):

# Wiring / Verdrahtung

> Prototype documentation. Confirm the pin labels on the exact XIAO ESP32-C3 board before soldering.

## GPIO assignment

| XIAO pin | ESP32-C3 GPIO | Function | Notes |
|---|---:|---|---|
| D7 / RX | GPIO20 | A02 UART RX | Sensor TX connects to ESP RX |
| D2 | GPIO4 | A02 power control | Drives the Pololu 2810 ON pin; do not power the A02 directly from the GPIO |
| D3 | GPIO5 | DS18B20 data | Add 4.7 kΩ pull-up to 3.3 V |
| D1 / A1 | GPIO3 | A02 trigger output | Connects to A02 RX (yellow); falling edge requests one measurement |

These assignments are substitutions at the top of `esphome/poolguard.yaml` and can be changed without editing the rest of the configuration.
GPIO2, GPIO8 and GPIO9 are ESP32-C3 strapping pins; none is used here.

## Block diagram

```text
Protected 18650
     │
     ├──────────────> XIAO battery/power input
     │
     ├─ Pololu 2810 ─────────────> A02YYUW VCC
     │                              A02 TX ─────> D7 / GPIO20
     │                              A02 RX <───── D1 / GPIO3
     │                              A02 GND ────> GND

3.3 V ── 4.7 kΩ ──┬──────────────> D3 / GPIO5
                  └──────────────> DS18B20 DATA
3.3 V ───────────────────────────> DS18B20 VCC
GND   ───────────────────────────> DS18B20 GND
```

## Important details

### A02 power switching

The distance sensor must be fully switched off during deep sleep. D2/GPIO4 is only a control signal for the Pololu 2810 ON input; do not power the sensor directly from the GPIO. Put the Pololu's physical slide switch in the off position so that its ON input controls the output. ON is active-high and the Pololu remains off when ON is low or disconnected. ESPHome initializes the GPIO output inactive; it is explicitly switched off before deep sleep, and the Pololu remains off when GPIO4 becomes high-impedance during reset or sleep. Confirm that the sensor supply is disconnected without back-powering through its UART line.

A series resistor on the A02 TX line may be useful, and the UART line should not be allowed to feed the powered-down sensor. The final switching circuit is still to be validated on the bench.

### A02 UART-Controlled sequence

The firmware keeps A02 RX/GPIO3 high while idle. For every measurement phase it
first establishes that idle level, enables the complete sensor supply through
the Pololu and waits 200 ms for startup. It then generates a 2 ms low pulse
followed by 78 ms high, so falling-edge triggers are 80 ms apart. The A02 reply
is read at 9600 baud, 8N1 on GPIO20 and accepted only when the
`FF Data_H Data_L Checksum` frame, checksum and distance range are valid. After
the trigger loop stops, the firmware allows another 70 ms for the final reply
before switching off the Pololu. A five-second burst therefore requests about
63 readings. The exact DYP sensor variant and its controlled-UART response must
still be confirmed on the physical prototype.

### DS18B20

Use the normal three-wire connection rather than parasite power. Fit an external pull-up of about 4.7 kΩ between 3.3 V and the data line. Keep the cable entry sealed and provide strain relief.

In normal battery operation Wi-Fi is disabled at boot. The ESP powers and
triggers the A02, evaluates the samples locally and returns directly to deep
sleep unless an event or the 30-wake periodic interval requires a report. Wi-Fi
is then enabled only for the report and is disabled again before sleep. Initial
Setup and Maintenance Mode explicitly keep Wi-Fi/API available; OTA is possible
during those existing online phases but does not cause an additional wake.

### Antenna

Place the adhesive antenna close to the plastic skimmer lid, away from the 18650 cell, sensor cable and large water-facing surfaces. Do not bend the active antenna area sharply.

## Before closing the housing

1. Verify polarity and resistance values.
2. Measure current in active mode and deep sleep.
3. Confirm that A02 current falls to effectively zero when switched off.
4. Confirm reliable Wi-Fi connection with the skimmer lid in its real position.
5. Run several hours with the housing open before sealing it.

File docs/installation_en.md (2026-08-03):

# Installation and calibration

## Project status

PoolGuard is still a prototype. The first step is only to test the 5 mm fit template. The final housing body and electronics lid will be published after the contour has been confirmed.

## 1. Test the fit template

1. Print `cad/stl/PoolGuard_Passschablone_V1.stl` with a reasonably fine layer height.
2. Supports should normally not be required for the flat template.
3. Place it gently into skimmer compartments 3 and 4.
4. Check the outer radius, inner radius and both straight sides.
5. Confirm that the original centre rib passes freely through the open template.
6. Record any error in millimetres and take photos if possible.

Do not cut, drill or glue the original lid yet.

## 2. Planned final housing installation

The final body will be a 60-degree annular sector matching compartments 3 and 4. The original centre rib remains untouched. The body sides will be bonded to the existing skimmer ribs with neutral-curing silicone suitable for permanent damp conditions.

The body is the permanently installed enclosure tub. The removable lower lid carries the battery holder, XIAO ESP32-C3 and wiring. The A02YYUW is mounted on the water-facing side of the removable lid.

## 3. Bench-test the electronics

Before installation:

1. Flash ESPHome with deep sleep temporarily disabled.
2. Confirm the DS18B20 address and temperature reading.
3. Compare A02 raw distance readings with a ruler.
4. Calibrate battery voltage against a multimeter.
5. Verify complete A02 power shutdown.
6. Test Wi-Fi at the actual skimmer location using the external antenna.

## 4. Calibrate water level

PoolGuard measures the distance from the sensor to the water surface. A smaller distance means a higher water level.

- `distance_empty_cm`: distance at the lowest acceptable water level.
- `distance_full_cm`: distance at the highest desired water level.

The firmware maps this range linearly to 0–100% and clamps values outside the range.

## 5. Calibrate pump detection

Pump detection is experimental. During each wake cycle, PoolGuard collects a burst of distance readings. The difference between the maximum and minimum distance is published as `Water Surface Motion`.

Procedure:

1. Record several cycles with the pump off.
2. Record several cycles with the pump running.
3. Choose a threshold that separates both groups as reliably as possible.
4. Adjust `pump_motion_threshold_cm` in the YAML.

Foam, wind, swimmers, rain or floating objects can cause false results. Never use this indication as a safety interlock.

## 6. Sealing

- Provide strain relief at every cable entry.
- Do not completely pot the electronics in silicone.
- Run a condensation test before final closure.
- Inspect the removable-lid seal periodically.
- Use only plastic-compatible neutral-curing sealants.

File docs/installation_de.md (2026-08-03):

# Montage und Kalibrierung

## Projektstatus

PoolGuard befindet sich noch im Prototypenstadium. Zuerst wird ausschließlich die Passform der 5-mm-Schablone geprüft. Der endgültige Body und der Technikdeckel werden erst nach bestätigter Passform veröffentlicht.

## 1. Passschablone testen

1. `cad/stl/PoolGuard_Passschablone_V1.stl` mit geringer Schichthöhe drucken.
2. Stützmaterial ist für die flache Schablone normalerweise nicht erforderlich.
3. Schablone ohne Gewalt in die Fächer 3 und 4 einsetzen.
4. Außenradius, Innenradius und beide geraden Seiten prüfen.
5. Prüfen, ob der Mittelsteg vollständig frei durch die offene Schablone läuft.
6. Abweichungen in Millimetern notieren und möglichst fotografieren.

Noch nichts am Originaldeckel schneiden, bohren oder verkleben.

## 2. Geplanter Einbau des finalen Bodys

Der Body wird später wie ein 60°-Kuchenstück geformt und sitzt direkt in den Fächern 3 und 4. Der Mittelsteg bleibt erhalten. Die Seiten werden mit neutralvernetzendem, für dauerfeuchte Umgebung geeignetem Silikon an den vorhandenen Skimmerstegen befestigt.

Der Body ist nur die dauerhaft eingeklebte Wanne. Der abnehmbare Deckel trägt Batteriehalter, XIAO ESP32-C3 und Kabel. Auf der Wasserseite des Deckels sitzt der A02YYUW.

## 3. Elektronik testen

Vor dem Einbau:

1. ESPHome-Konfiguration mit deaktiviertem Deep Sleep flashen.
2. DS18B20-Adresse und Temperaturwert prüfen.
3. A02-Rohdaten prüfen und mit einem Zollstock vergleichen.
4. Batteriespannung gegen ein Multimeter kalibrieren.
5. A02-Stromabschaltung testen.
6. WLAN-Empfang mit der externen Antenne am realen Einbauort prüfen.

## 4. Wasserstand kalibrieren

PoolGuard misst den Abstand vom Sensor zur Wasseroberfläche. Ein kleinerer Abstand bedeutet einen höheren Wasserstand.

- `distance_empty_cm`: Abstand beim niedrigsten noch zulässigen Wasserstand.
- `distance_full_cm`: Abstand beim höchsten gewünschten Wasserstand.

Die Firmware rechnet den Bereich linear auf 0–100 % um und begrenzt Werte außerhalb des Bereichs.

## 5. Pumpenerkennung kalibrieren

Die Pumpenerkennung ist experimentell. Pro Wachzyklus werden mehrere schnelle Messwerte gesammelt. Die Differenz aus größtem und kleinstem Abstand wird als `Water Surface Motion` veröffentlicht.

Vorgehen:

1. Mehrere Zyklen mit ausgeschalteter Pumpe aufzeichnen.
2. Mehrere Zyklen mit laufender Pumpe aufzeichnen.
3. Einen Schwellwert wählen, der beide Gruppen möglichst zuverlässig trennt.
4. Den Wert `pump_motion_threshold_cm` in der YAML anpassen.

Schaum, Wind, Badebetrieb, Regen oder schwimmende Gegenstände können die Erkennung verfälschen. Der Status darf nicht für sicherheitskritische Steuerungen verwendet werden.

## 6. Abdichtung

- Kabeldurchführungen mit Zugentlastung ausführen.
- Elektronik nicht direkt mit Silikon übergießen.
- Vor dem endgültigen Verschließen einen Kondensationstest durchführen.
- Deckeldichtung regelmäßig kontrollieren.
- Nur kunststoffverträgliche, neutralvernetzende Dichtstoffe verwenden.

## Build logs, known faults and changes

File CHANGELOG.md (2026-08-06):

# Changelog

All notable project changes will be documented here.

## Unreleased

### Added

- Initial English and German project documentation
- Prototype ESPHome configuration for XIAO ESP32-C3
- A02YYUW UART frame parser
- DS18B20 water-temperature sensor configuration
- Experimental pump detection from distance-measurement spread
- Hardware bill of materials and wiring notes
- German and English installation guides
- Parametric 5 mm fit-template source for skimmer compartments 3 and 4

### Pending validation

- Physical fit of inner and outer radii
- Final GPIO assignment
- A02 power-switch circuit
- Deep-sleep current and expected battery life
- Pump-detection threshold
- Final body and removable electronics lid
- Final Buy Me a Coffee profile link

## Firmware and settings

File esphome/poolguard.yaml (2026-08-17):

substitutions:
  device_name: poolguard
  friendly_name: PoolGuard

  # XIAO ESP32-C3 pin map: D7=GPIO20, D2=GPIO4, D3=GPIO5, D1=GPIO3.
  # None of these are ESP32-C3 strapping pins (GPIO2/GPIO8/GPIO9).
  a02_rx_pin: GPIO20
  a02_power_pin: GPIO4
  a02_trigger_pin: GPIO3
  one_wire_pin: GPIO5

  # Normal low-power operation. The desired wake-to-wake period and periodic
  # report cadence are persistent Home Assistant numbers defined below.
  detection_burst_duration: 5s
  a02_startup_duration: 200ms
  a02_trigger_low_duration: 2ms
  a02_trigger_interval_rest: 78ms
  a02_frame_wait_after_triggers: 70ms

  # Motion-calibration sampling. Initial Setup Mode itself is controlled by a
  # persistent flash-backed flag and therefore needs no compile-time switch.
  calibration_window_seconds: "5"
  calibration_windows: "12"

  # Pool geometry. Adjust these two values for another cylindrical pool.
  pool_diameter_m: "5.0"
  pool_max_depth_cm: "120.0"

  # Low-water hysteresis in centimetres. The actual minimum safe depth is an
  # editable Home Assistant number and MUST be determined on the real skimmer.
  low_water_hysteresis_cm: "1.0"
  # A single low reading is treated as a candidate only. Low Water becomes
  # active after this many consecutive measurement cycles below the limit.
  low_water_confirm_cycles: "3"

  # Fallback motion thresholds used until a complete valid calibration exists.
  pump_motion_threshold_cm: "1.5"
  person_motion_threshold_cm: "3.0"
  pump_confirm_cycles: "2"
  person_on_confirm_cycles: "1"
  person_off_confirm_cycles: "2"

  # After the first reported person detection, suppress further person-triggered
  # reports for three hours. Detection continues locally during the lockout,
  # but it does not wake Wi-Fi/API again just because motion toggles.
  person_alert_cooldown_minutes: "180"

  # After a failed non-critical report, keep measuring locally but skip Wi-Fi
  # for this many wakes. New critical events bypass the backoff immediately.
  communication_retry_backoff_wakes: "5"

  # Installation-dependent mechanical safety clearance below the A02; adjust
  # it to the real sensor mounting. Flood Risk uses the existing robust lower
  # distance quantile, never a single minimum sample.
  sensor_flood_risk_distance_cm: "5.0"
  sensor_flood_risk_clear_hysteresis_cm: "1.0"

  # Person/activity detection deliberately uses a higher entry threshold than
  # the simple midpoint between Pump and Person profiles. Clearing uses the
  # midpoint. Together with two independent half-burst checks this provides
  # hysteresis without delaying a real detection across multiple wake cycles.
  person_profile_on_fraction: "0.65"
  person_profile_clear_fraction: "0.50"

esphome:
  name: ${device_name}
  friendly_name: ${friendly_name}
  comment: Battery-powered pool-skimmer level, temperature and motion monitor
  includes:
    - poolguard_rtc.h
  on_boot:
    priority: 600
    then:
      - lambda: |-
          ESP_LOGI("poolguard",
                   "BOOT DIAGNOSTICS: reset_reason=%d wakeup_cause=%d",
                   (int) esp_reset_reason(),
                   (int) esp_sleep_get_wakeup_cause());
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

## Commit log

2026-08-03 Add hardware bill of materials
2026-08-03 Add wiring documentation
2026-08-03 Add CAD project notes
2026-08-03 Add parametric fit-template source
    [PoolGuard_Passschablone_V1.scad]
2026-08-03 README: Projektbeschreibung und Home-Assistant-Anwendungsfälle ergänzen
2026-08-03 README: Bauteileliste und Affiliate-Hinweis ergänzen
2026-08-03 README: link current 3D files
2026-08-03 Update 3D print file path
2026-08-03 README: document Pololu 2810 A02YYUW power switch
2026-08-03 Use coffee-style PayPal support button
2026-08-03 Add friendly PayPal support button
2026-08-03 Add friendly German PayPal support button
2026-08-03 Use larger friendly PayPal support button
2026-08-03 Größeren freundlichen PayPal-Support-Button verwenden
2026-08-03 Tighten PayPal support button layout
2026-08-03 Make PayPal support button slightly narrower
2026-08-03 Add RTC state for low-power detection
2026-08-03 Add low-power pump and person detection
2026-08-03 Track low water state in RTC
2026-08-03 Add battery level and low water warning
2026-08-03 Add guided motion calibration for pump and pool activity
2026-08-03 Document guided pump and pool-activity calibration
2026-08-03 Kalibriermodus für Pumpe und Badeaktivität dokumentieren
2026-08-03 Fix calibration YAML and persist learned thresholds promptly
    [poolguard.yaml]
2026-08-03 Add one-point water level calibration and pool volume
2026-08-03 Document water-level reference calibration and pool volume
2026-08-03 Wasserstandsreferenz und Poolvolumen dokumentieren
2026-08-03 Abschrägung des Bodys erklären
2026-08-03 Keep A02 off while awaiting calibration
2026-08-04 Fix image filename case in README
2026-08-04 Update README_DE.md with printer details
    Added information about the 3D printer used for printing.
2026-08-06 Correct XIAO ESP32-C3 GPIO assignments
    [poolguard.yaml]
2026-08-06 Remove battery level monitoring
2026-08-06 Improve maintenance and calibration UX
2026-08-06 Replace compile-time calibration mode with persistent initial setup
    [poolguard.yaml]
2026-08-06 Update PoolGuard documentation for current firmware
2026-08-06 Update English PoolGuard documentation for current firmware
2026-08-14 Document A02 UART variants and Pololu power switching
2026-08-14 Add A02 controlled UART triggering
2026-08-14 Optimize low power reporting and HA state retention
2026-08-14 Add configurable low power intervals and device status
2026-08-14 Polish final documentation and calibration guidance
2026-08-15 Stabilize person detection and event reporting
    [poolguard.yaml]
2026-08-15 Document enclosure moisture protection and silica gel
2026-08-15 Restore poolguard configuration after failed connector update
    [poolguard.yaml]
2026-08-15 Update print statement from 'Hello' to 'Goodbye'
2026-08-15 Enhance Home Assistant integration examples in README
    Updated Home Assistant automation examples and descriptions for PoolGuard, including person detection, low-water warnings, pump safety shutdown, and circulation detection.
2026-08-15 Suppress pump drawdown false low-water alarms
2026-08-17 Harden PoolGuard detection and reporting
    - accept water level only from quiet reliable bursts
    - prevent person activity from self-classifying as pump
    - allow person detection while pump is already running
    - add cumulative 3 mm reliable water-level reporting
    - start person alert cooldown only after successful reporting
    - add communication retry backoff
    - add sensor flood-risk detection
    - make Distance to Water quiet-only
    - use independent wake sequence for wake-aware streaks
    [poolguard.yaml]
2026-08-17 Update documentation for final PoolGuard architecture
    - document reliability, simplicity, battery and failsafe principles
    - document quiet-only water-level handling and reporting
    - document pump/person precedence and communication backoff
    - add sensor flood-risk documentation
    - update Home Assistant automations and dashboard guidance
    - add algae-risk advisory
    - document seasonal operation and known limitations
    - remove installation-specific identifiers and obsolete guidance
2026-08-21 Add backlog section for future hardware revisions
    Added a backlog section detailing future hardware revisions for battery voltage measurement and its implications.
2026-08-21 Add backlog section for future hardware revisions
    Added a backlog section detailing future plans for battery voltage measurement and its implementation considerations.
